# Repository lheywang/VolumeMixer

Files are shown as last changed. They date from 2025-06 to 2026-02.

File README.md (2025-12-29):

# Volume mixer

Volume mixer is a device that enable to configure the volume of different apps on the PC as well as the master volume directly by interracting with sliders on the device.
Additionnally, oled screens are used to show different informations about each slider, including : A logo of the managed app, an volume value, and a mute status.

All of this code is working on Linux and Windows.

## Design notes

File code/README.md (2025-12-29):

# Code
This is the core of the VolumeMixer, since all of this stuff handle the interractions between the hardware and the computer.
 
The whole software is splitted in half : 
- The host part
- The device part

## Host
The host part, wrotten in Python ensure control of audio volumes in both Linux and Windows.\*
This part is responsible for the overall management of the tool, the device only respond to commands.

> \*Actually, there is some functionnality variations between both, making the Linux version a bit more complete.

## Device
The device part is written in native C for STM32 targets.
It was wrote using STM32CubeIDE 1.19.

The project is named "board", and contain all the needed code.

The project is based arround a folder named "lib", which contain a lot of code that is platform agnostic.
It could be easily reused accross a lot of different devices !

There's one large file, fsm/fsm.c - .h that are the "heart" of the device, and handle all of the necessary actions.

All of the remaining code is basically setup, drivers for some devices and interrupts routines.

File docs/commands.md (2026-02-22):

# Commands

In this file, let's explore how the host computer and the device communicate.
This device only act as a slave, which mean that it will never send data by itself. It will only respond to a previous command.

There is five known commands :

- SHUTD : Shut down the device. Require to press the button to start it.
- RESET : Reset the device to the base state.
- DCONF : Set calibration data of the device.
- CONNC : Connect the host to the device (and thus, block any further connections).

- ASYNC : Sync applications that are known to the device with the apps that are currently in use.
- UICON : Update icons. This commands is generally sent after an ASYNC command that may returned wrong apps.
- SLPOS : Return the position of the sliders, in %.

Internally, theses commands are executed as a state machine, that execute the correct steps in the correct order.

## Protocol

```
START;<CMD_NAME>;<LEN>;<DATA>;<CRC32>;END
```

With :

- CMD_NAME : The command name, on 8 bytes of data. Can be
- LEN : The length of the data received, in bytes (char). Expressed as 3 integer (up to 999)
- DATA : Custom data passed. Always formatted as JSON
- CRC32 : Checksum of the whole message up to now (CRC32 and END excluded).

The command is borned with START and END tokens to clearly identify the
start and end of a said command. Theses are used to identify by both end over the serial bus to 
trigger the processing of the next one.

The DATA is generally encoded as JSON data, which will be detailled in the few next paragraphs.

## Data exhange

For each command, this is the field you may find :

(All of the exhanges are seen as the host, so TX = command SENT, RX = command received).

### SHUTD

This command does not send or receive additionnal data.

### RESET

This command does not send or receive additionnal data.

### CONNC

This command is used to start a communication with an host and a device.
The device answer OOK or NOK depending on it's previous state.

### ASYNC

This command receive the list of applications that shall be displayed on the device and used as it.

TX : The host list the device that shall be used.

```javascript
{
    "apps" : [
        {"1"    : CRC32["master"]},
        {"2"    : CRC32["discord.exe"]},
        {"3"    : CRC32["firefox.exe"]},
        {"4"    : CRC32["UNUSED"]},
        {"5"    : CRC32["Valorant.exe"]}
    ]
}
```

And the device respond the apps that are already known (and thus, displayed) with a match = true.
Otherwise a match = false will indicate that the app is not know of the device.

```javascript
{
    "match" : "false",
    "apps" : [
        {
            "1"     : CRC32["master"],
            "match" : 1
        },
        {
            "2"     : CRC32["discord.exe"],
            "match" : 1
        },
        {
            "3"     : CRC32["firefox.exe]",
            "match" : 2"
        },
        {
            "4"     : CRC32["UNUSED]",
            "match" : 1
        },
        {
            "5"     : CRC32["Valorant.exe]",
            "match" : 0
        }
    ]
}
```

There's three state : true (1), known (2) and false (0). If the app is not actually displayed (known or false), the device will start
to update the icon on the screen. The difference is that for "known", the device already know the icon in it's memory, and will thus
use the icon stored internally. Only the "false" shall trigger an UICON command.

### UICON

This command is used to uptate an icon (generally, this command follow an ASYNC command). It contain the app, the slider and the data of the icon.

```javascript
{
    "icon" : {
        "slider"    : "1",
        "app"       : CRC32["world-of-tank.exe"],
        "icon"      : "xxxxxxxxxxxxxxxxxxxxxxxxxxxxxxxxxxxxxxxxxxxxxxxxxxxxxxxxxxxxxxxxxxxxxxxxxxxxxxxxxxxxxxxxxxxxxxxxxxxxxxxxxxxxxxxxxxxxxxxxxxxxxxxx",
        "store"     : 1
    }
}
```

The device respond with the same header, and data as OOK to acknowledge the data, or not (NOK).

### SLPOS

This command is used to fetch the position of the sliders on the device. This is the most common command to be runned. There's no data sent alongside
of the command, but the device respond with the following data structure :

```javascript
{
    "sliders" : [
        {
            "1"     : 082,
            "1M"    : 1
        },
                {
            "2"     : 029,
            "2M"    : 0
        },
                {
            "3"     : 050,
            "3M"    : 1
        },
                {
            "4"     : 100,
            "4M"    : 1
        },
                {
            "5"     : 000,
            "5M"    : 1
        }
    ]
}
```

For each slider, there's two field : n and nM. n refer to the slider, and it's value to the value of the volume (in %). nM refer to a boolean, which is mute or not.

### DCONF

This command configure the device. It shall not be run continuously by the host (but once at the manufacturing step).

It take some data in input :

```javascript
{
    "cal" : [
        {
            "1OFF"  : "+0.082",
            "1G"    : "1.01"
        },
                {
            "2OFF"  : "+0.029",
            "2G"    : "1.09"
        },
                {
            "3OFF"  : "+0.050",
            "3G"    : "1.00"
        },
                {
            "4OFF"  : "+0.000",
            "4G"    : "1.12"
        },
                {
            "5OFF"  : "-0.012",
            "5G"    : "0.98"
        }
    ],
    "gain" : "1.09",
    "offset": "0.012",
    "device": "2025118H1D9",
}
```

The device respond with an ACK or NACK.

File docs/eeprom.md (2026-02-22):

# EEPROM

The EEPROM located on the board is used to store different things :

- Calibration and device info.
- Known icons, to fetch them faster than before.

Since the EEPROM is 64 kbits, it can store up to 60 icons. In practice, that's not the case,
arround 4 to 10 will be stored.

## System informations

System informations are also available, such as :

- Serial Number\*, to identify which devices are which (mostly in case of multiple systems on the same host).
- Data to know at which offsets are placed images.

## Calibration data

To ensure a smooth and regular experience, calibration data will be stored into the EEPROM, and used
when calculating the volume from the potentiometer. This include :

- An ADC gain error
- An ADC offset
- Per channel calibration :
  - A channel offset
  - A channel gain error

All of this done is to ensure the smallest differences between channels of the devices, of all devices.

## Icons

> [!IMPORTANT]
> Icons aren't anymore stored on the EEPROM, but rather loaded by the host OS, on demand.
> This prevent for overusing the EEPROM, saving bits, and gaining little to no benefits.
> Thus, this following part became irrelevant.

Each icon is 30 x 30 px, which means 900 bits of data (screens are black and white). Each of them is
stored on four consecutive pages.

## Data emplacement

On the eeprom, the data is stored in the following pages :

### Calibration data :

This data is stored on page 0 and 1, with the following placement :

| Byte  | Variable | Description |
| ----- | --- | --- |
| 0-1 | MARKER | Constant to 0xbeef |
| 2-9 | ID | Device SN |
| 10-11 | ADC_OFF  | ADC offset (in raw code, 0-4096) |
| 12-13 | CH1_OFF  | ADC offset for channel 1 (raw code) |
| 14-15 | CH2_OFF  | ADC offset for channel 2 (raw code) |
| 16-17 | CH3_OFF  | ADC offset for channel 3 (raw code) |
| 18-19 | CH4_OFF  | ADC offset for channel 4 (raw code) |
| 20-21 | CH5_OFF  | ADC offset for channel 5 (raw code) |
| 22 | ADC_GAIN | ADC Gain error (in signed Q1.6 format) |
| 23 | CH1_G | ADC Gain error for channel 1 (S Q1.6)  |
| 24 | CH2_G | ADC Gain error for channel 2 (S Q1.6)  |
| 25 | CH3_G | ADC Gain error for channel 3 (S Q1.6)  |
| 26 | CH4_G | ADC Gain error for channel 4 (S Q1.6)  |
| 27 | CH5_G | ADC Gain error for channel 5 (S Q1.6)  |
| 28-31 | EMPTY | UNUSED |
| 32-33 | SLIDER1  | HASH for slider 1 before shutdown |
| 34-35 | SLIDER2  | HASH for slider 2 before shutdown |
| 36-37 | SLIDER3  | HASH for slider 3 before shutdown |
| 38-39 | SLIDER4  | HASH for slider 4 before shutdown |
| 40-41 | SLIDER5  | HASH for slider 5 before shutdown |
| 42-59 | UNUSED | For future usage |
| 60-63 | CHKSM | CRC32 of the config |

### Address reference

This data refer to the EEPROM addresses used to store each image. Each line refer to an HASH (HASH of the APP Name) and an ADDRESS on 12 bits.
This is stored on 2 pages (2 and 3).

| Byte  | Variable | Description |
| ----- | --- | --- |
| 0-3 | IMG1 | HASH:ADDR for image 1 |
| 4-7 | IMG2 | HASH:ADDR for image 2 |
| 8-11  | IMG3 | HASH:ADDR for image 3 |
| 12-15 | IMG4 | HASH:ADDR for image 4 |
| 16-19 | IMG5 | HASH:ADDR for image 5 |
| 20-23 | IMG6 | HASH:ADDR for image 6 |
| 24-27 | IMG7 | HASH:ADDR for image 7 |
| 28-31 | IMG8 | HASH:ADDR for image 8 |
| 32-35 | IMG9 | HASH:ADDR for image 9 |
| 36-39 | IMG10 | HASH:ADDR for image 10 |
| 40-43 | IMG11 | HASH:ADDR for image 11 |
| 44-47 | IMG12 | HASH:ADDR for image 12 |
| 48-51 | IMG13 | HASH:ADDR for image 13 |
| 52-55 | IMG14 | HASH:ADDR for image 14 |
| 56-59 | IMG15 | HASH:ADDR for image 15 |
| 60-63 | CHKSM | CRC32 for the addresses config |

### Images

Then, we found images, splitted on four pages each.
Images are written randomly on the EEPROM address space to get a near constant wear levelling of the cells. Thus, addresses are always multiple
of 128 (size of an image).
First image start on byte 64, then 192, then 320...

There is about 63 possibles icons on the EEPROM, but only 15 are used, leaving 75% of the chip for wear levelling usage.

---

\* The serial number is expressed as the following form, on 8 bytes : YYMDHXDY
With :

- YY the year(only last two digits)
- M the month (0-12)
- D the day (0-31)
- H is constant to 'H'
- X is the hardware revision (0-...)
- D is constant to 'D'
- Y the device on that day (0-...)

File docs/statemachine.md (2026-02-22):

# State Machine

## Steps

The whole device and host are based on a state machine, to track the different steps of connection.
There's different states :

- BOARD_INIT
- WAIT_FOR_CONNECT
- WAIT_FOR_COMMAND
- WAIT_FOR_RESPONSE

Theses firsts steps :

### BOARD_INIT

In this steps, triggered by electrical reset, or RESET command, the board reset itself to it's default state.
In this mode, the both the device and host aren't open to commands.

### WAIT_FOR_CONNECT

In this second step, the link between host and device is established. This is done by the host to open all of the COM ports on the device, and reading on it for 500 ms.
Meanwhile the device send a specific string such as : "START;CONNC;021;{"state":"available"};49934095;END" every 250 ms.

Once such a message is received by the host, the connection request is sent, and the device acknoweledge.
Both the host and device then go on a private state where they're connection is reserved.

### WAIT_FOR_COMMAND

For this third step, the device is waiting for a command. This doesn't mean it does nothing, it's only waiting for a command to arrive.
In background, the position of sliders are sampled regularly to ensure a quick response to command.

Thats the task of the host to request the values rather than filling input buffers with junk.

### WAIT_FOR_RESPONSE

This is the last step, it's directly followed by a command write. It does not last a lot.

## Implementation

The core of this FSM is developped into the [fsm.c](https://github.com/lheywang/VolumeMixer/blob/main/code/board/Core/Src/fsm/fsm.c) file.

That's this file, which contain quite a lot of code that control most, if not all the behaviors of the 
device.

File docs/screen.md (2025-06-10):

# Screen

The screen onboard is used to prompt to the user some cool infos, such as the icon of the app currently, the volume or a MUTE flag.

## Layout

With dimensions such as 128 x 32 px, the screen isn't that big.

The layout is the following :

| Pixels | Function | Details |
| --- | --- | --- |
| 0-6 px | BLANK | |
| 7-23 px | Volume in % | Two chars, 16 x 16 px each |
| 24-35 px | BLANK | |
| 36-58 px | Speaker logo | Show the actual volume (graphically). |
| 59- 70 px  | BLANK | |
| 71-79 px | MUTE indicator | Four char, 8 x 8 px each (MUTE only). Blank if not mute. |
| 80-91 px | BLANK | |
| 92-121 px  | App Icon | 30 x 30 px icon (image treatement is done on the host device) |
| 122-128 px | BLANK | |

[Font source](https://lexus2k.github.io/ssd1306/ssd1306__fonts_8c_source.html)

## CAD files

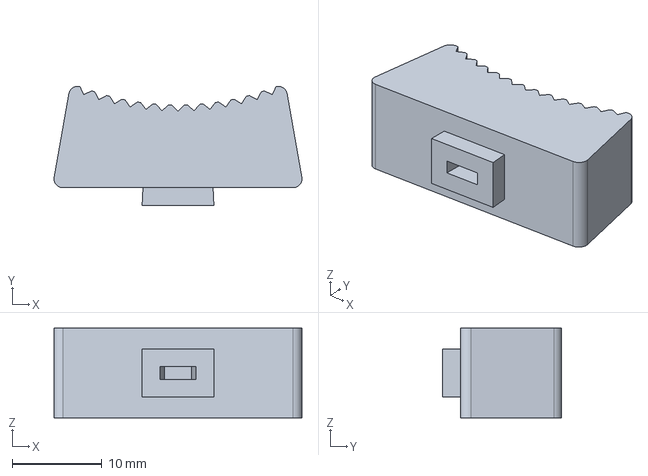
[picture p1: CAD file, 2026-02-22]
case/capuchon slider V2 1.step
27.6 x 13.3 x 10.0 mm

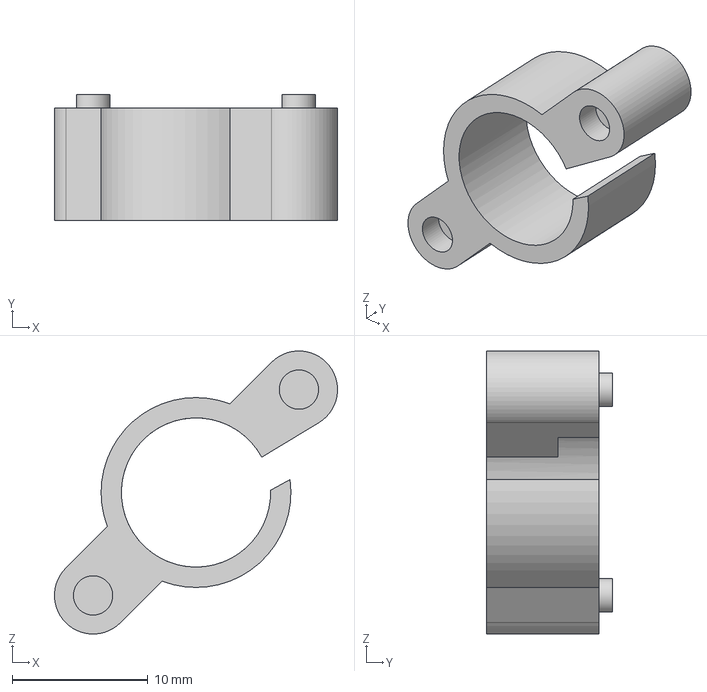
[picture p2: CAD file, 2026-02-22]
case/Support Sensor part 1 V2 x5.step
20.9 x 9.28 x 20.9 mm

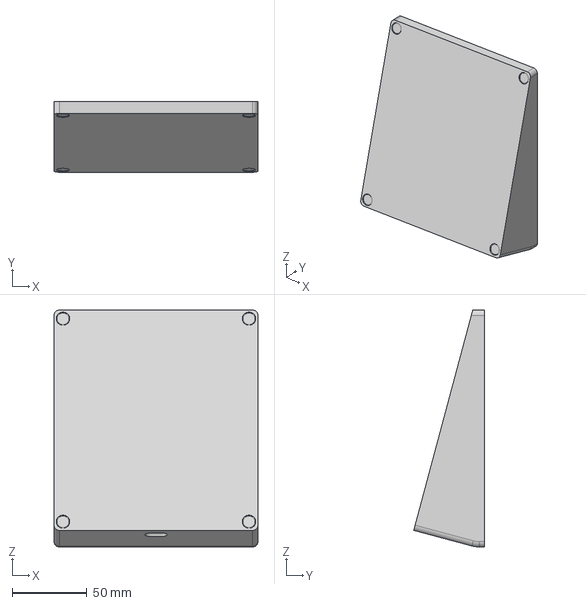
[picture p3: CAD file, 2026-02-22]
case/BOTTOM V2.step
136.0 x 47.1 x 158.0 mm

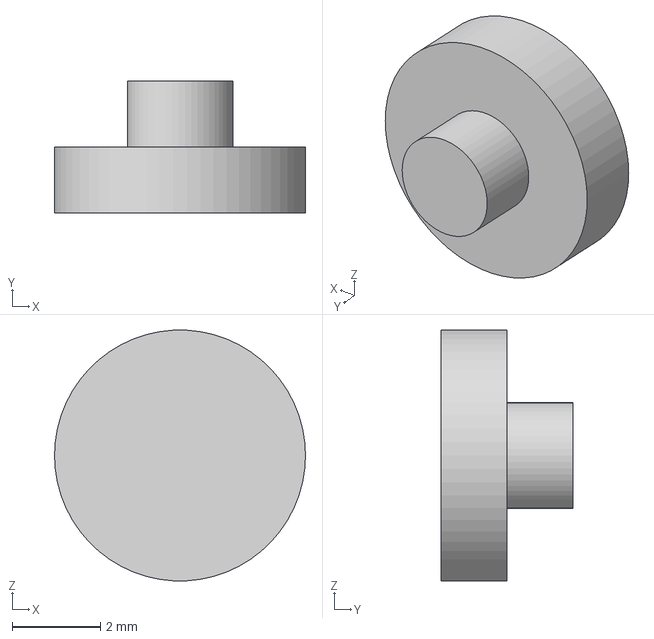
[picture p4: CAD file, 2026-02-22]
case/Support sensor part 2 V2 x10.step
5.70 x 3.00 x 5.69 mm

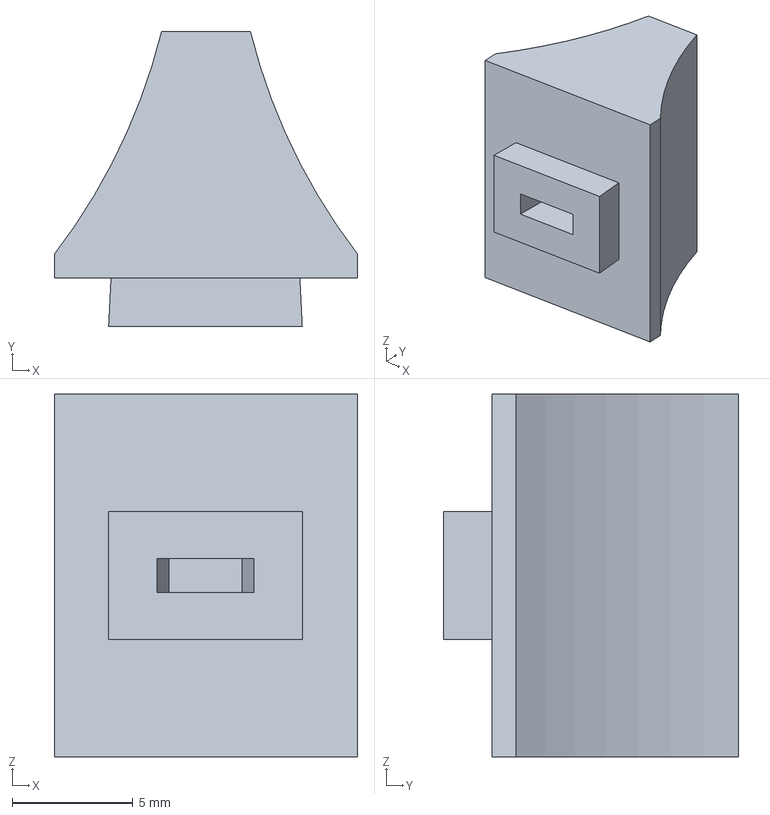
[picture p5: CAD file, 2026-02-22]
case/capuchon slider 3.step
12.5 x 12.2 x 15.0 mm

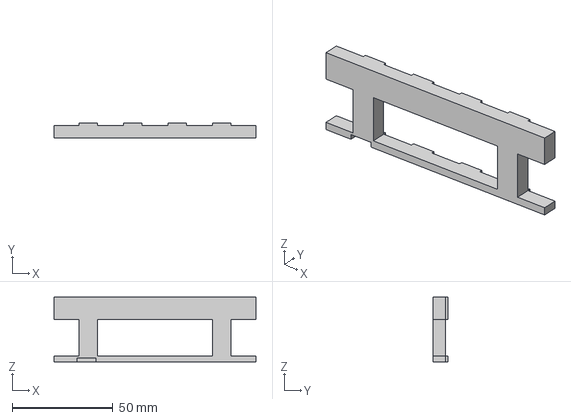
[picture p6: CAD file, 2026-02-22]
case/SUPPORT SCREEN V1.step
100.0 x 7.26 x 32.0 mm

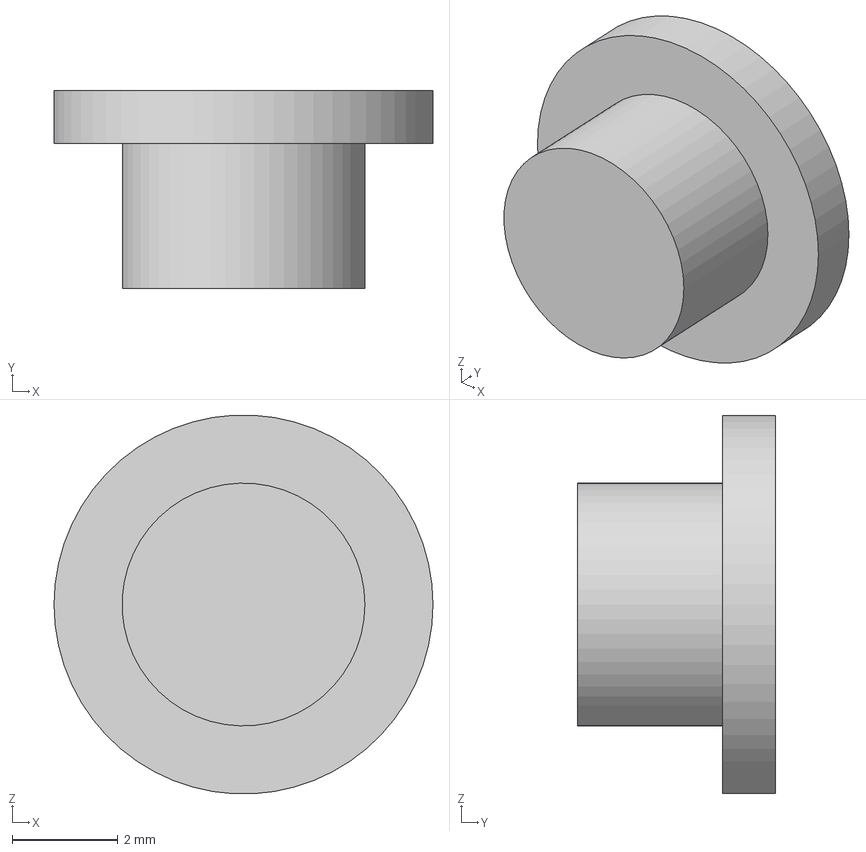
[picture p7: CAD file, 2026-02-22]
case/Capuchon vis top V2.step
7.18 x 3.75 x 7.17 mm

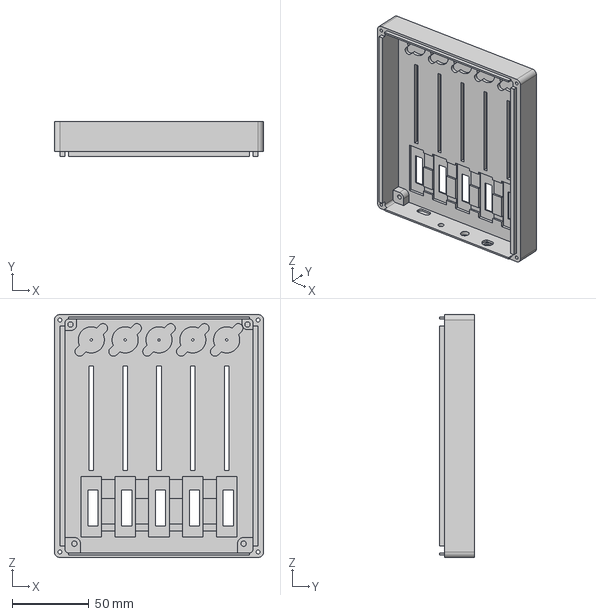
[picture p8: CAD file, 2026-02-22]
case/TOP CASE V2.step
136.0 x 22.5 x 158.0 mm

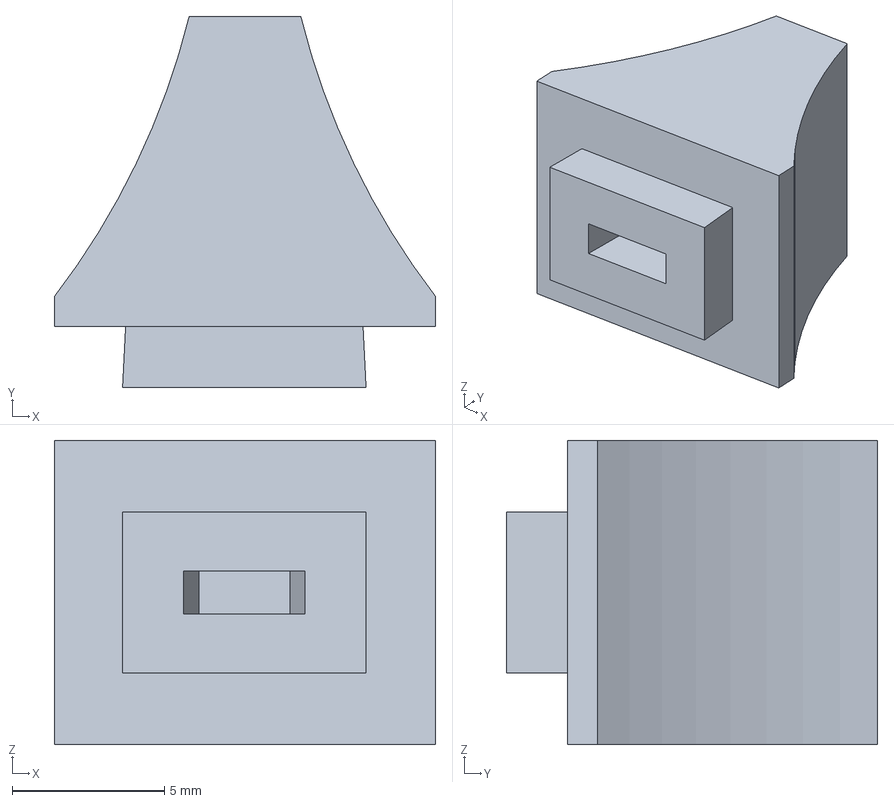
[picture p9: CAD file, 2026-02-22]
case/capuchon slider V2 2.step
12.5 x 12.2 x 10.0 mm

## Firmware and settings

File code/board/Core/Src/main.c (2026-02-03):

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
/* Includes ------------------------------------------------------------------*/
#include "main.h"
#include "usb_device.h"

/* USER CODE BEGIN Includes */
// ST
#include "usbd_cdc_if.h"

// Others files
#include "config.h"
#include "fsm/fsm.h"
#include "utils/init.h"
#include "handlers/leds.h"
#include "handlers/timers.h"

#include "utils/logger.h"

/* USER CODE END Includes */

ADC_HandleTypeDef hadc1;

I2C_HandleTypeDef hi2c2;

TIM_HandleTypeDef htim2;
TIM_HandleTypeDef htim15;
TIM_HandleTypeDef htim16;

TSC_HandleTypeDef htsc;

UART_HandleTypeDef huart3;
DMA_HandleTypeDef hdma_usart3_tx;

void SystemClock_Config(void);
static void MX_GPIO_Init(void);
static void MX_DMA_Init(void);
static void MX_ADC1_Init(void);
static void MX_I2C2_Init(void);
static void MX_TSC_Init(void);
static void MX_USART3_UART_Init(void);
static void MX_TIM2_Init(void);
static void MX_TIM15_Init(void);
static void MX_TIM16_Init(void);
/* USER CODE BEGIN 0 */
extern uint8_t isr_message[ISR_MESSAGE_SIZE];
extern uint8_t msg_available;

// From fsm/fsm.c
extern int output_volumes[5];

// Private variables
uint8_t uart_message[96] = { 0 };

/* USER CODE END 0 */

/**
  * @brief  The application entry point.
  * @retval int
  */
int main(void)
{

  /* MCU Configuration--------------------------------------------------------*/

  /* Reset of all peripherals, Initializes the Flash interface and the Systick. */
  HAL_Init();

  /* Configure the system clock */
  SystemClock_Config();

  /* USER CODE BEGIN SysInit */
  /*
   * Call theses here, to ensure the logger will be effective immediately.
   * After regeneration, they may be re-called, but we don't care ! We'll overwrite the same parameters.
   */
  MX_DMA_Init();
  MX_USART3_UART_Init();

  /* USER CODE END SysInit */

  /* Initialize all configured peripherals */
  MX_GPIO_Init();
  MX_DMA_Init();
  MX_ADC1_Init();
  MX_I2C2_Init();
  MX_TSC_Init();
  MX_USART3_UART_Init();
  MX_USB_DEVICE_Init();
  MX_TIM2_Init();
  MX_TIM15_Init();
  MX_TIM16_Init();
  /* USER CODE BEGIN 2 */

  // Init the board
  board_init();

  /* USER CODE END 2 */

  /* Infinite loop */
  /* USER CODE BEGIN WHILE */
  // int size = 0;
  while (1)
  {
	  fsm_update();
    /* USER CODE END WHILE */

    /* USER CODE BEGIN 3 */
  }
  /* USER CODE END 3 */
}

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


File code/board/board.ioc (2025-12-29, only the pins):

Mcu.UserName=STM32F302C8Tx
PA0.GPIO_Label=Slider0
PA0.Signal=ADC1_IN1
PA1.GPIO_Label=Slider1
PA1.Signal=ADC1_IN2
PA10.Signal=I2C2_SDA
PA11.Signal=USB_DM
PA12.Signal=USB_DP
PA13.Signal=SYS_JTMS-SWDIO
PA14.Signal=SYS_JTCK-SWCLK
PA15.GPIO_Label=led_mute0
PA15.Signal=GPIO_Output
PA2.GPIO_Label=Slider2
PA2.Signal=ADC1_IN3
PA3.GPIO_Label=Slider3
PA3.Signal=ADC1_IN4
PA4.GPIO_Label=Slider4
PA4.Signal=ADC1_IN5
PA5.GPIO_Label=dbg_led
PA5.Signal=GPIO_Output
PA6.GPIO_Label=vref_dig
PA6.Signal=ADCx_IN10
PA7.GPIO_Label=vref_ana
PA7.Signal=ADC1_IN15
PA8.GPIO_Label=led_mute1
PA8.Signal=GPIO_Output
PA9.Signal=I2C2_SCL
PB0.GPIO_Label=vref_usb
PB0.Signal=ADC1_IN11
PB1.GPIO_Label=led_mute4
PB1.Signal=GPIO_Output
PB10.GPIO_Label=dbg_tx
PB10.Signal=USART3_TX
PB11.Signal=TSC_G6_IO1
PB12.Signal=TSC_G6_IO2
PB13.Signal=TSC_G6_IO3
PB14.Signal=TSC_G6_IO4
PB15.GPIO_Label=led_mute2
PB15.Signal=GPIO_Output
PB2.GPIO_Label=led_mute3
PB2.Signal=GPIO_Output
PB3.Signal=TSC_G5_IO1
PB4.Signal=TSC_G5_IO2
PB5.GPIO_Label=dbg_io1
PB5.Signal=GPIO_Output
PB6.Signal=TSC_G5_IO3
PB7.GPIO_Label=dbg_io0
PB7.Signal=GPIO_Output
PB8.Signal=USART3_RX
PB9.GPIO_Label=power_on
PB9.Signal=GPIO_Input
PC13.GPIO_Label=led_red
PC13.Signal=GPIO_Output
PF0-OSC_IN.Signal=RCC_OSC_IN
PF1-OSC_OUT.GPIO_Label=dbg_bp
PF1-OSC_OUT.Signal=GPIO_Input

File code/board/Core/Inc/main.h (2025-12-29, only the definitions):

#define led_red_Pin GPIO_PIN_13
#define led_red_GPIO_Port GPIOC
#define led_green_Pin GPIO_PIN_14
#define led_green_GPIO_Port GPIOC
#define led_blue_Pin GPIO_PIN_15
#define led_blue_GPIO_Port GPIOC
#define dbg_bp_Pin GPIO_PIN_1
#define dbg_bp_GPIO_Port GPIOF
#define Slider0_Pin GPIO_PIN_0
#define Slider0_GPIO_Port GPIOA
#define Slider1_Pin GPIO_PIN_1
#define Slider1_GPIO_Port GPIOA
#define Slider2_Pin GPIO_PIN_2
#define Slider2_GPIO_Port GPIOA
#define Slider3_Pin GPIO_PIN_3
#define Slider3_GPIO_Port GPIOA
#define Slider4_Pin GPIO_PIN_4
#define Slider4_GPIO_Port GPIOA
#define dbg_led_Pin GPIO_PIN_5
#define dbg_led_GPIO_Port GPIOA
#define vref_dig_Pin GPIO_PIN_6
#define vref_dig_GPIO_Port GPIOA
#define vref_ana_Pin GPIO_PIN_7
#define vref_ana_GPIO_Port GPIOA
#define vref_usb_Pin GPIO_PIN_0
#define vref_usb_GPIO_Port GPIOB
#define led_mute4_Pin GPIO_PIN_1
#define led_mute4_GPIO_Port GPIOB
#define led_mute3_Pin GPIO_PIN_2
#define led_mute3_GPIO_Port GPIOB
#define dbg_tx_Pin GPIO_PIN_10
#define dbg_tx_GPIO_Port GPIOB
#define led_mute2_Pin GPIO_PIN_15
#define led_mute2_GPIO_Port GPIOB
#define led_mute1_Pin GPIO_PIN_8
#define led_mute1_GPIO_Port GPIOA
#define led_mute0_Pin GPIO_PIN_15
#define led_mute0_GPIO_Port GPIOA
#define dbg_io1_Pin GPIO_PIN_5
#define dbg_io1_GPIO_Port GPIOB
#define dbg_io0_Pin GPIO_PIN_7
#define dbg_io0_GPIO_Port GPIOB
#define power_on_Pin GPIO_PIN_9
#define power_on_GPIO_Port GPIOB

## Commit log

2025-05-19 debut du projet
    [volume-mixer.kicad_pcb, volume-mixer.kicad_sch]
2025-05-22 test 1
    [untitled.kicad_sch, volume-mixer.kicad_pcb, volume-mixer.kicad_sch]
2025-05-23 avancer du layout
    [untitled.kicad_sch, volume-mixer.kicad_pcb, volume-mixer.kicad_sch]
2025-05-26 Capacitive sensor layout
    [untitled.kicad_sch, volume-mixer.kicad_pcb, volume-mixer.kicad_sch]
2025-05-26 Added structure of a global HAL for any board : PCB or devboard
2025-05-31 Added config file and corrected build issues
    [volume-mixer.kicad_pcb]
2025-05-31 Added hardware config to files and corrected build issues
    [main.c, main.h]
2025-06-02 imagine ça marche
    [untitled.kicad_sch, volume-mixer.kicad_sch]
2025-06-03 je sais jamais quoi mettre en commentaires
    [sensor pcb.kicad_pcb]
2025-06-10 Added abstraction class for the device (empty for now)
2025-06-10 merged ?!?
    [untitled.kicad_sch, volume-mixer.kicad_pcb, volume-mixer.kicad_sch]
2025-06-11 Added first elements of the device management system
2025-06-11 Added commands and corrected scale factor for the conversion between dB and %
    [commands.py, device.py, utils.py]
2025-06-21 Tried some elements with USART_RTO. Does not work...
    [main.c]
2025-06-23 Finished parser of the command, now it's reliable enough for our use case
2025-06-25 Added I2C scanner for the STM32 and tested TSC
2025-06-26 Added maths library for conversion between custom types
    [SQ1.6 format error calcs.xlsx]
2025-06-27 Added an EEPROM parser and EEPROM builder to handle configuration of the device (not fully tested for now)
2025-06-30 Added support for negative ADC codes for negatives offsets
2025-06-30 Added tests for the ADC conversion function
2025-06-30 Added a digital filter for the raw ADC codes, to reduce noise
2025-06-30 Added the first bases for the screen driver
2025-07-01 Added simulation of the speaker repartition
    [SPEAKER repartition.xlsx]
2025-07-01 Corrected last buffers issues
    [main.c]
2025-09-24 Updated driver
2025-09-24 Finished SSD1306 driver
2025-09-24 Added USB-Device functions and modified them
2025-09-25 Added EEPROM Driver (could not test it, 24CL32 is not compatible
    [24cl64.c]
2025-09-26 Added ADC Sampler code
2025-12-29 Removed old Cube project
    [SPEAKER repartition.xlsx, SQ1.6 format error calcs.xlsx]
2025-12-29 Added the "real" CubeIDE project for the device. Include a lot of the previously developped codes and merged all of them
2025-12-29 Moved project to CubeIDE 2.0.0 and re-created all drivers files
2026-02-03 Changed prints into debug logs
2026-02-03 Corrected invalid dict errors
    [commands.py, device.py]
2026-02-03 Added the calibration procedure, need to implemented
2026-02-04 Updated main calibration procedure
2026-02-04 Added image buffer in RAM of the device
2026-02-04 Updated calibration algorithm
2026-02-04 Corrected errors while parsing the DCONF command
    [init.c]
2026-02-04 Corrected errors within parsing of some commands
    [init.c]
2026-02-05 Improved ADC calibration procedure. Not perfect for now, need for more works
2026-02-05 Corrected errors in the C project
    [init.c]
2026-02-05 Added temp file, IA generated to compute the calibrations values. Need to be tested
2026-02-22 Added case 3D files
    [BOTTOM V2.step, Capuchon vis top V2.step, SUPPORT SCREEN V1.step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]

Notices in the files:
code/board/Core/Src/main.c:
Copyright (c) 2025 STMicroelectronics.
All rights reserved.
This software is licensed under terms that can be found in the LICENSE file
